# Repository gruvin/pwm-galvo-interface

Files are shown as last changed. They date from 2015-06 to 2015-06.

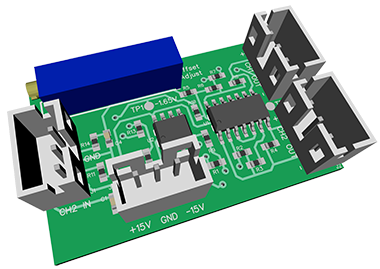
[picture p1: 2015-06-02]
images/laser-galvo-interface-3d.png

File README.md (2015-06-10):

###A two channel, 3.3V PWM to Balanced +/-5VDC converter, for use with laser galvanometers

This interface board takes two raw PWM (0-3.3V) inputs from a microcontroller, low pass filters 
them and translates the analogue result into two +/-5VDC, balanced outputs -- the latter being 
what many laser galvanometer drivers require as inputs. Power (+/-15VDC) is acquired from one 
of the two galvanometer driver boards.

![https://raw.githubusercontent.com/gruvin/pwm-galvo-interface/master/images/laser-galvo-interface-3d.png]
(https://raw.githubusercontent.com/gruvin/pwm-galvo-interface/master/images/laser-galvo-interface-3d.png)

The above image is about double actual size, on my iMac 27" screen. (109DPI)

This design (using DipTrace) has been built and tested. It works surprisingly well. I run the PCM frequency 
at between 800KHz and 1MHz on the PWM input side (from an Arduino or Maximite, for example) and the results 
at the other end of the galvanometer interface, mirrors, laser etc is pretty darn good -- especially considering I didn't add any AC bypass capaitors in the op-amp feedback paths. Slew rates are still more than acceptable.

The high frequency PWM allows an order of magnitude higher laser direction precision. However, the board will 
work down to around 200KHz -- and lower if the LPF capacitance is increased. But then the laser starts to make 
rounded corners, instead of crisp, sharp turns of the kind I need for a project in mind. It seems that even cheap Chinese galvanometers are astonishingly fast and accurate! 

Having completed this exercise, I now intend removing all the analogue electronics of the galvanometer 
interface itself and making my own PID controller, fully digital -- except the galvanometers themselves, 
of course. There will no longer be a need for this board. But it was well worth the experiment.

## NOTES

The file `galv-pos-re.dch` is a reverse engineered schematic (DipTrace) of the galvonometer position feedback circuit, as found on the Chinese laser galv boards I purchased on eBay. Those clever peoples have used a cheaper, non-linear, "one IR LED and two IR photo-diodes in photovoltaic mode (balanced)" arrangement inside the galvanometers and instead built a slightly more complex differential amplifier, incorporating some clever lineraity compensation circuity -- which appears to even include varying the LED brightness slightly, along with direct voltage curve augmentation at the input of the differential amplifier. I've never seen anything quite like this before -- though I suppose it's all too common, in reality. Respect! :-P

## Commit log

2014-03-07 Added "-1.65V" reference note alongside TP1, on PCB.
2014-03-08 Production file freeze (archive). PCB's ordered from ITeadStudio.com.
    [BoardOutline.gbr, Bottom.gbr, BottomMask.gbr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]
2014-03-21 Removed orphanned pad on PCB
2014-03-22 R14 was unconnected. Guess I never ran the schematic verification tool. :-/
2015-05-21 The power supply input (j4) labels were reversed!! Nothing some more magic smoke couldn't fix!! Grr.
2015-06-02 Updated Schematic and PCB
2015-06-02 Updated production files
    [BoardOutline.gbr, Bottom.gbr, BottomDimension.gbr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]
2015-06-06 + Fixed regression of PCB file (from multi-machine edit without pull first. Grrr.) + Removed paste from TP2 and GND test points + Updated all production files.
    [Bottom.gbr, BottomDimension.gbr, Top.gbr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]
